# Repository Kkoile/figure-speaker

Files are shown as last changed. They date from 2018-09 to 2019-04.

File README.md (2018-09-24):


# Figure Speaker
This project is a Raspberry Pi based audio player which plays songs or audiobooks depending on a NFC Tag which is placed on the player. The NFC Tags can be attached to the bottom of a figure. This is an intuitive way for children to select the audiobooks they want to here based on the figures they associate with it.

The main feature of this project is a Spotify integration which lets you access all your favourite songs and audio books you already pay for every month.
By using the audio server [Mopidy](https://www.mopidy.com/) internally, further cloud services can be integrated really easily.
Box

## Feature List
 - Spotify integration
 - Easy to maintain and register figures through a web application
 - Portable by using a power bank
 - Play local mp3 files
 - Configure volume
 - Max volume is configurable
 - Define what happens after the figure is replaced on the audio player
   - Play the track from the beginning
   - Play the track where you left off
 - Easy to connect to new WiFi by creating an AdHoc network if the box cannot connect to WiFi
 - Update Manager which will allow you to receive the latest features without opening the box
 - Open for other cloud services
 - Automated tests to ensure quality

### Spotify Integration
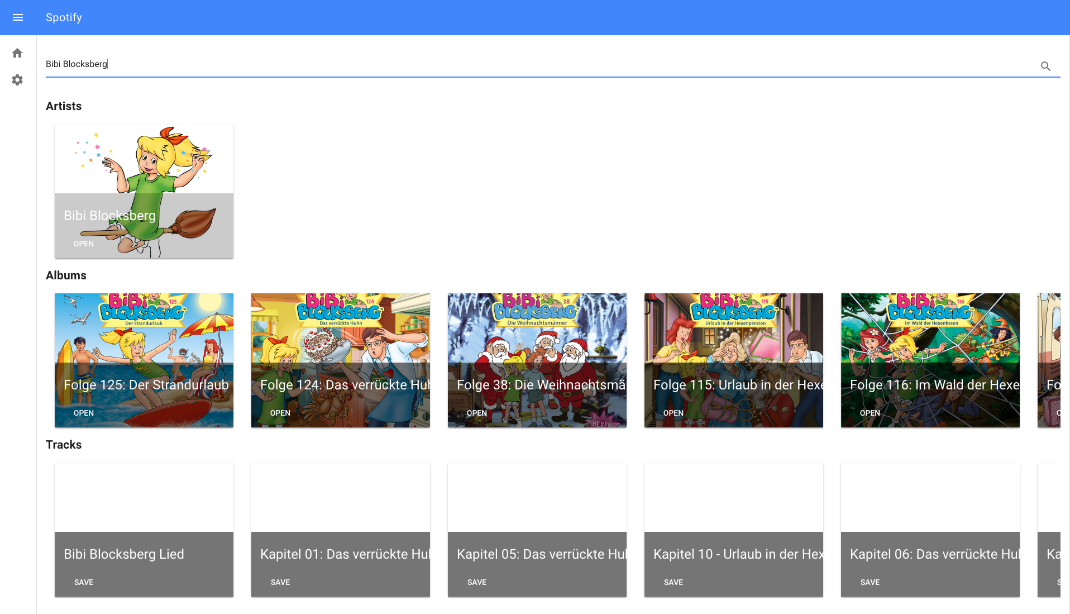
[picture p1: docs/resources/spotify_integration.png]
Spotify Integration


### Settings
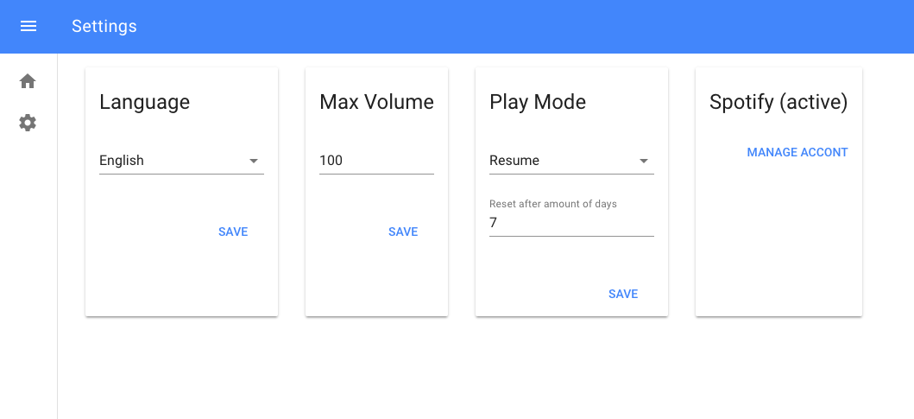
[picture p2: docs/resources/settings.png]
Settings


## Manual
See [Manual](docs/manual.md) for finding out how to use figure-speaker.

## Setup
See [Setup](docs/setup.md) for setting up the Raspberry Pi.

## Assembly
In chapter [Assembly](docs/assembly.md) I documented instructions how to build the hardware of the figure speaker.

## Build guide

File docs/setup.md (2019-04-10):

# How to Setup Figure-Speaker on a Raspberry Pi Image
These steps need to be followed in order to setup a raspberry pi image with the figure speaker environment. 
## Flash Raspberry Pi Image
The project is only tested with a raspbian image. However, other raspberry pi images should work as well.

Follow the instructions at [Raspberry Pi Setup Instructions](https://www.raspberrypi.org/documentation/installation/installing-images/) in order to flash an image. 
Download the lite image from [Raspberry Pi Downloads](https://www.raspberrypi.org/downloads/raspbian/). There is no need for the Desktop version, because the figure-speaker won't have a display attached.

Connect the SD card of your raspberry pi to your computer and flash the image via etcher.

### Create an SSH File
Create an empty file named `ssh` at root level of the sd card in order to access the raspberry pi later on.

### Provide WiFi Credentials (optional)
In order to directly access your raspberry pi over via ssh, you can provide the wifi credentials on sd card level. Without doing this you need to plug in your raspberry pi to your network via ethernet.

Create a file called `wpa_supplicant.conf` at root level of the sd card. Edit the file and place the following content with your modifications regarding the credentials:
```
country=DE
ctrl_interface=DIR=/var/run/wpa_supplicant GROUP=netdev
update_config=1

network={
    ssid="<SSID>"
    psk="<PASSWORD>"
}

```

### Start Raspberry Pi
Put the sd card into your raspberry pi and start it. It should connect to the configured wifi automatically.
Connect to the raspberry pi via ssh:
```
ssh pi@raspberrypi.local
```
Use the default password `raspberry` for authentication.
You should directly change the default password by entering the command `passwd`

From now on, you have two options: Either download and execute a setup script, which will execute every step necessary automatically, or do each step manually.
If you decide for the automatic script, all you have to do is to execute the following command and then restart the raspberry pi:
```
curl https://raw.githubusercontent.com/Kkoile/figure-speaker/master/setup.sh -o ~/setup.sh | ~/setup.sh
```
If you want to execute each step manually, follow the following commands on this page.

## Set Audio Volume to Maximum
The volume will be handled later by our application. In order to be able to get the maximum volume you should set it on the raspberry pi:
```
amixer set PCM -- 100%
```

## Enable SPI Interface
Type `sudo raspi-config` and go to `Interfacing Options`. Select `SPI` and make sure to enable it. 

## Install Mopidy
Mopidy is the audio server which connects to spotify and other providers. You can find more about mopidy [here](https://docs.mopidy.com/en/latest/).
In order to install mopidy on the raspberry pi follow the [instructions](https://docs.mopidy.com/en/latest/installation/debian/#debian-install).

Depending on the mopidy extensions you want to include you should install them. For example the spotify extension:
```
sudo apt-get install mopidy-spotify
``` 

Modify the file `~/.config/mopidy/mopidy.conf` and add the following lines to it:
```
[local]
media_dir = ~/.config/figure-speaker/files
```
Run `mopidy local scan` in order for mopidy to scan the files in there.

### Install MPC (Optional)
In order to test if mopidy is working, you can install a mopidy client like `mpc`:
```
sudo apt-get install mpc
```
This allows you to play mp3 files on your raspberry pi, or if already configured, extensions like spotify.
For the full documentation type `man mpc`. If you only want to test the audio output you can use the following code snippet:
```
curl https://www.sample-videos.com/audio/mp3/crowd-cheering.mp3 -o test.mp3
mpc add file:///home/pi/test.mp3
mpc play
```
Use `mpc stop` to stop playing the current audio file.

## Install Node.js
Node.js is the environment in which figure-speaker is written. Hence, to be able to execute the application you need to install it. 
```
curl -sL https://deb.nodesource.com/setup_8.x | sudo -E bash -
sudo apt-get install -y nodejs
```
Change the directory of installing global npm modules, in order to reduce permission errors. Follow this [link](https://docs.npmjs.com/getting-started/fixing-npm-permissions#option-two-change-npms-default-directory) to do so.

## Install Figure-Speaker
Figure-Speaker is written as a global npm module. So we can install it by executing the following command:
```
sudo npm install -g figure-speaker
```
Don't mind the vast amount of error logs...

You can test the installation by typing `figure-speaker` in the command line. This should start the server. The frontend should now be available at `http://figure-speaker:3000` or `http://figure-speaker.local:3000` (MacOsX).

We want our application to always start when booting raspberry pi. To achieve this, we create a service file which we can then manage with `systemctl`.
Create a file `figure-speaker.service`:
 ```
 sudo touch /etc/systemd/system/figure-speaker.service
 sudo chmod 664 /etc/systemd/system/figure-speaker.service
 ```
And paste the following content in it. You should change the spotify credentials according to your spotify app.
//TODO: link to another chapter where this is explained
```
[Service]
WorkingDirectory=/home/pi/
ExecStart=/home/pi/.npm-global/bin/figure-speaker
Restart=always
StandardOutput=syslog
StandardError=syslog
SyslogIdentifier=figure-speaker
User=pi
Group=pi
Environment=NODE_ENV=production SPOTIFY_CLIENT_ID=<SPOTIFY_CLIENT_ID> SPOTIFY_CLIENT_SECRET=<SPOTIFY_CLIENT_SECRET> GPIO_INCREASE_VOLUME_BUTTON=27 GPIO_DECREASE_VOLUME_BUTTON=22

[Install]
WantedBy=multi-user.target
```

Execute the following command:
```
sudo systemctl enable figure-speaker
```
Now, either start the service directly with `sudo systemctl start figure-speaker`, or reboot the raspberry pi.
 
You can always see the current logs by executing `journalctl -u figure-speaker -f`

## Install Update Manager
```
sudo npm install -g figure-speaker-update-manager
```
Create a file `figure-speaker-update-manager.service`:
 ```
 sudo touch /etc/systemd/system/figure-speaker-update-manager.service
 sudo chmod 664 /etc/systemd/system/figure-speaker-update-manager.service
 ```
And paste the following content in it.
```
[Service]
WorkingDirectory=/home/pi/
ExecStart=/home/pi/.npm-global/bin/figure-speaker-update-manager
Restart=always
StandardOutput=syslog
StandardError=syslog
SyslogIdentifier=figure-speaker-update-manager
User=pi
Group=pi
Environment=NODE_ENV=production 

[Install]
WantedBy=multi-user.target
```

Execute the following command:
```
sudo systemctl enable figure-speaker-update-manager
```
Now, either start the service directly with `sudo systemctl start figure-speaker-update-manager`, or reboot the raspberry pi.
 
You can always see the current logs by executing `journalctl -u figure-speaker-update-manager -f`

## Install WiFi Connector
```
sudo npm install -g figure-speaker-wifi-connector
```
Create a file `figure-speaker-wifi-connector.service`:
 ```
 sudo touch /etc/systemd/system/figure-speaker-wifi-connector.service
 sudo chmod 664 /etc/systemd/system/figure-speaker-wifi-connector.service
 ```
And paste the following content in it.
```
[Service]
WorkingDirectory=/home/pi/
ExecStart=/home/pi/.npm-global/bin/figure-speaker-wifi-connector
Restart=always
StandardOutput=syslog
StandardError=syslog
SyslogIdentifier=figure-speaker-wifi-connector
User=root
Group=root
Environment=NODE_ENV=production 

[Install]
WantedBy=multi-user.target
```

Execute the following command:
```
sudo systemctl enable figure-speaker-wifi-connector
```
Now, either start the service directly with `sudo systemctl start figure-speaker-wifi-connector`, or reboot the raspberry pi.
 
You can always see the current logs by executing `journalctl -u figure-speaker-wifi-connector -f`

## Configure Ad Hoc Wifi
//TODO document how to configure ad hoc network and expose figure-speaker-wifi-connector

https://lcdev.dk/2012/11/18/raspberry-pi-tutorial-connect-to-wifi-or-create-an-encrypted-dhcp-enabled-ad-hoc-network-as-fallback/

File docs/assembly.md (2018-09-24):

# Assembly
In this chapter you will find instructions about how to build the hardware of figure speaker.
## Connect Raspberry Pi to Modules
This section instructs you how to connect the Raspberry Pi to the different hardware modules. 

### What you need
- [Raspberry Pi 3](https://www.amazon.de/Raspberry-Pi-Model-ARM-Cortex-A53-Bluetooth/dp/B01CD5VC92/)
- [SD Card](https://www.amazon.de/SanDisk-Ultra-microSDHC-Speicherkarte-Adapter/dp/B073S9SFK2/)
- [RFID Reader](https://www.amazon.de/gp/product/B01M28JAAZ/)
- [Power Bank](https://www.amazon.de/gp/product/B00FAU7ZB2)
- [Micro USB Cable](https://www.amazon.de/gp/product/B01NAMTC5T)
- [Jumper Cable](https://www.amazon.de/gp/product/B00OL6JZ3C)
- [Buttons](https://www.amazon.de/gp/product/B0749KNQNH)
- 2x 1 kΩ Resistor
- [Speaker](https://www.amazon.de/gp/product/B073XH8KK8)
- [Amplifier](https://www.amazon.de/HER-Digital-Amplifier-PAM8403-Stereos/dp/B073HFGZQC)
- [Aux Cable](https://www.amazon.de/gp/product/B00DRCTB58)
- [Breadboard](https://www.amazon.de/gp/product/B0728HZHTR/)
- [Copper wire](https://www.amazon.de/gp/product/B0043DQ7WK)

1) If not already done, you need to solder the pins to the Raspberry Pi and the RFID Reader.
2) Connect the aux cable to the amplifier module. I cut of one end of the aux cable and strip of the isolation. Then the copper wire needs to be soldered to the amplifier.
3) Solder the speakers to the amplifiers.
4) Connect circuit bord to Raspberry Pi. I used jumper cables for connecting the the modules.
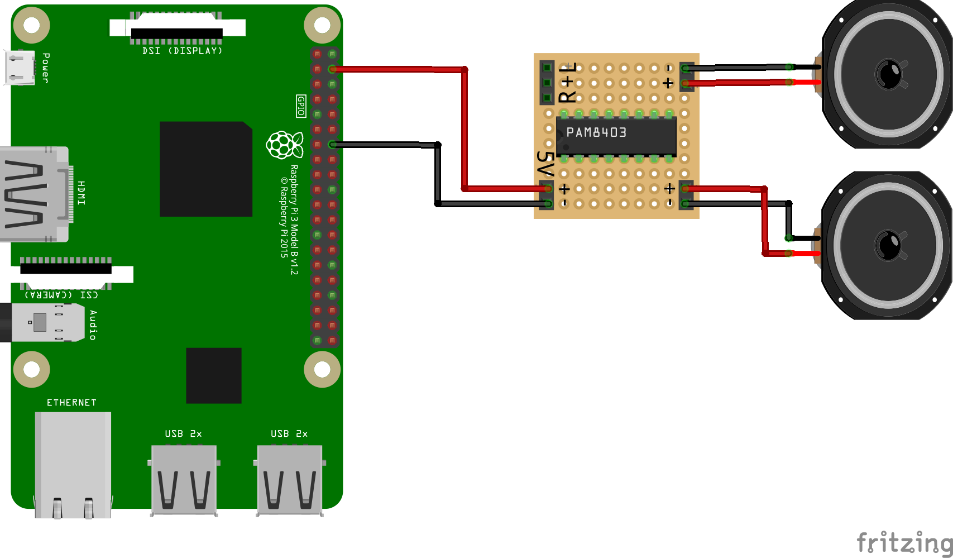
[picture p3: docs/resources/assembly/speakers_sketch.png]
Speakers

5) Create a circuit board with resistors for the volume buttons. You can find a sketch of the circuit board in the image below. I used 1 kΩ resistors. Make sure that the cables to the buttons are long enough to be placed where you want them to be.
6) Connect this circuit board to Raspberry Pi.
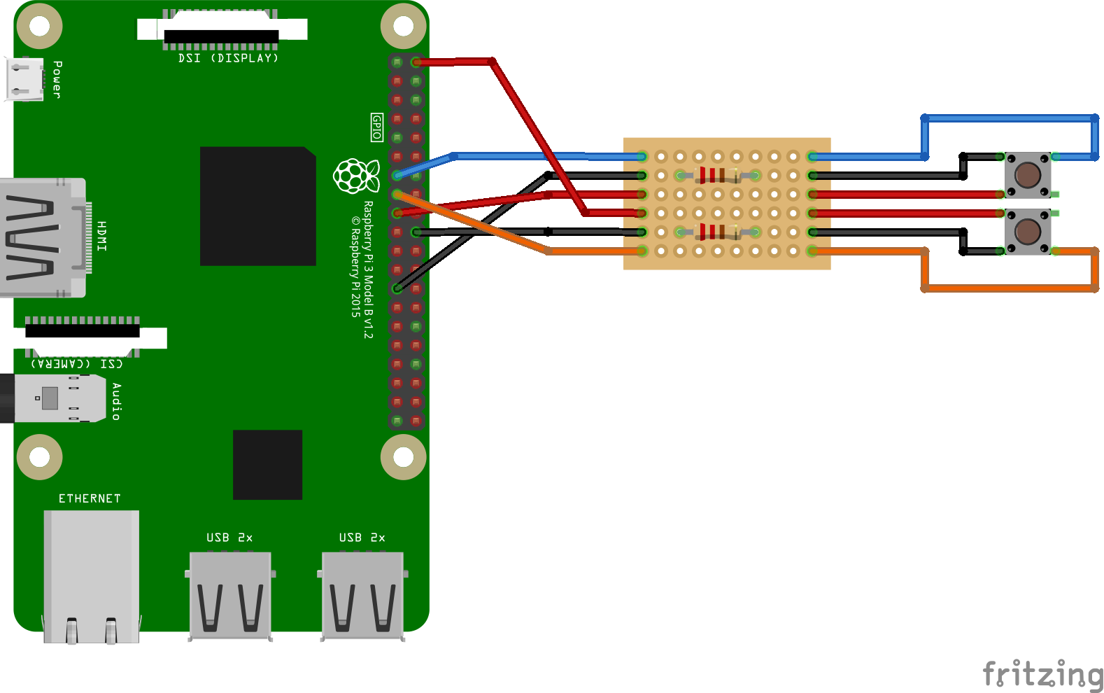
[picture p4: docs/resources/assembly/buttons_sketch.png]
Buttons

7) Connect RFID Reader to Raspberry Pi.
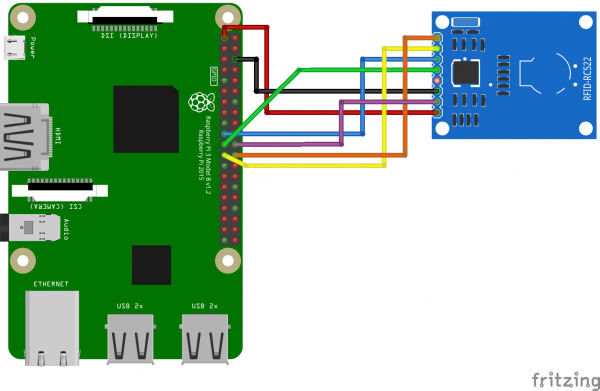
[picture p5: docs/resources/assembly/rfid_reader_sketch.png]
RFID Reader

Image is taken from "https://tutorials-raspberrypi.de/raspberry-pi-rfid-rc522-tueroeffner-nfc/"

after you have wired everything, you can test if it works. In order to setup the Raspberry Pi itself from a software point of view, see chapter [Setup](./setup.md). I advise you to do the final wiring while building the box (see below). Otherwise it will be complicated to place the modules in the box.

## Build the Box
I know that there are a lot of ways to build a simple box and I am not a carpenter. So this way to build a wooden box might not be the best, but it is simple and works. However, feel free to give feedback or adjust the instructions to your needs.

Please Note: The wooden parts of the box don't need to be perfectly cut, because I wrap the whole box with foam plates, in order to make them "child safe" and robust against falling to the ground etc. 
 
The sizes of this box depend on the power bank you use and the size of the speakers. That's why there are no measures for the outlets of the power bank in order to charge it or turn it on and off.
### What you need
- 4x square mouldings: 20mm * 20mm * 140mm
- 4x captive nuts: M4 * 6
- 4x countersunk threaded screw: M3 * 16mm
- 4x wood plates for the side: 150mm * 140mm * 4mm
- 2x wood plates for the bottom/top: 150mm * 150mm * 4mm
- 20x screw spax: M4 * 12mm
- 4x countersunk threaded screw: M2 * 10mm incl. nuts
- 10x countersunk threaded screw: M3 * 10mm incl. nuts
- 4x cylinder head threaded bolt: M3 * 16mm incl. 12 nuts
- metal perforated tapes
- foam plates: about 10mm thick

### Blueprints
Two bottom / top plates:
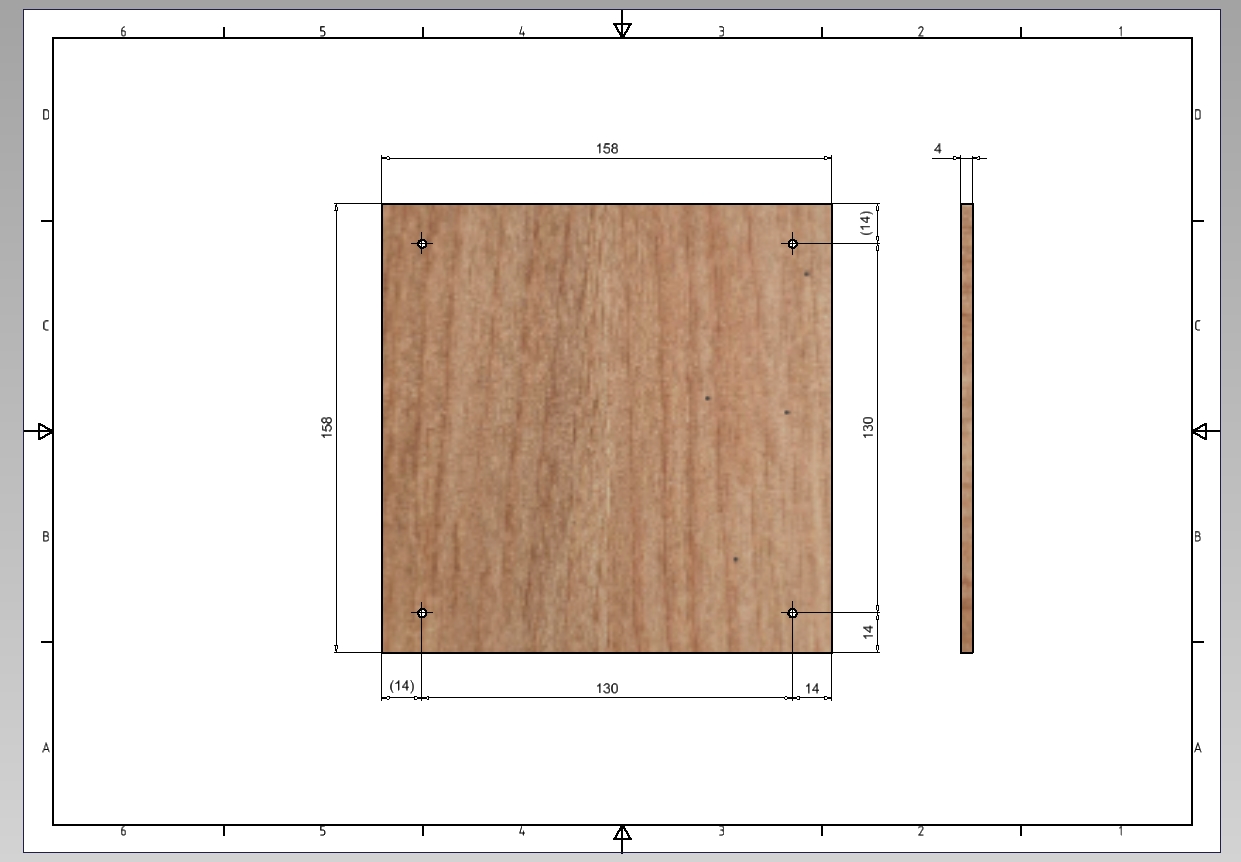
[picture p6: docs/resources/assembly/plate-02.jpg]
Bottom / Top Plates

Two side plates:
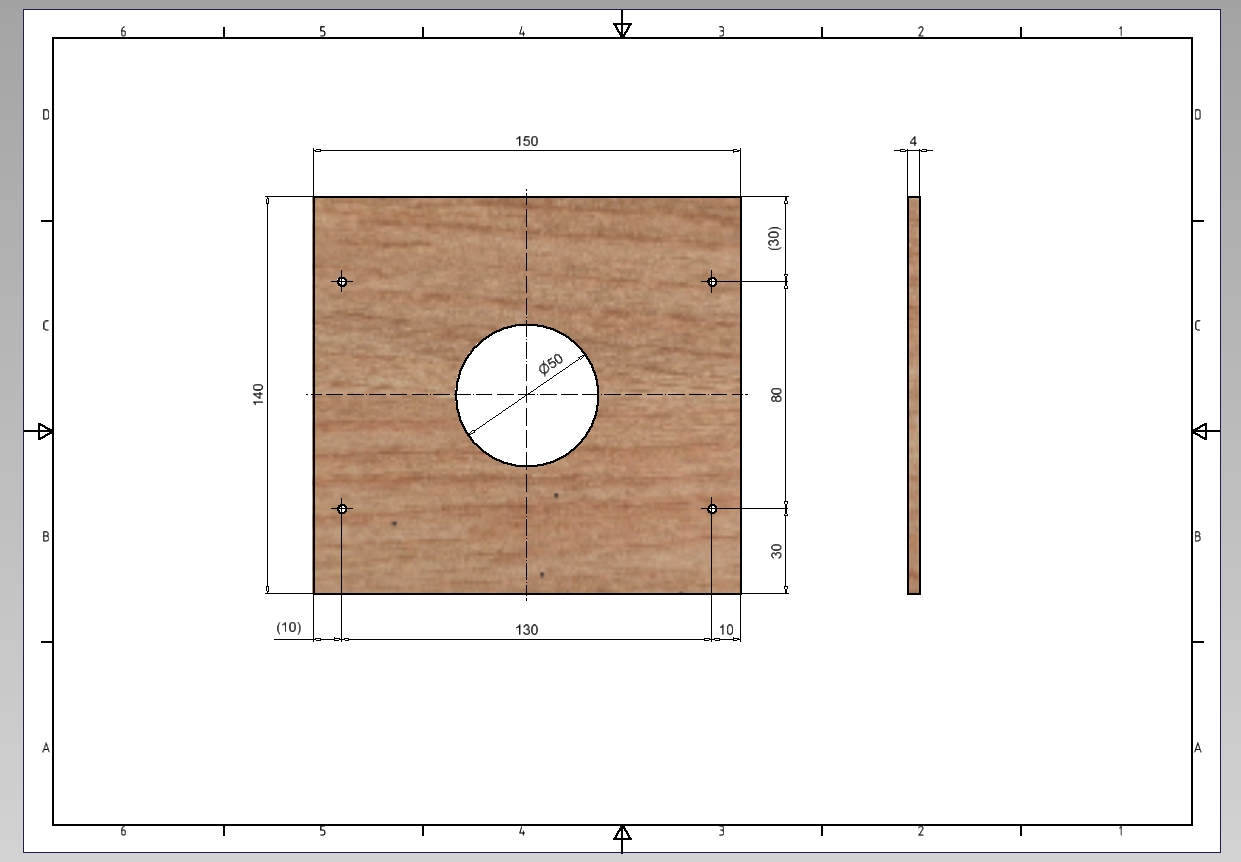
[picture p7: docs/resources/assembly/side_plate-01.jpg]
Side Plates

Front plate:
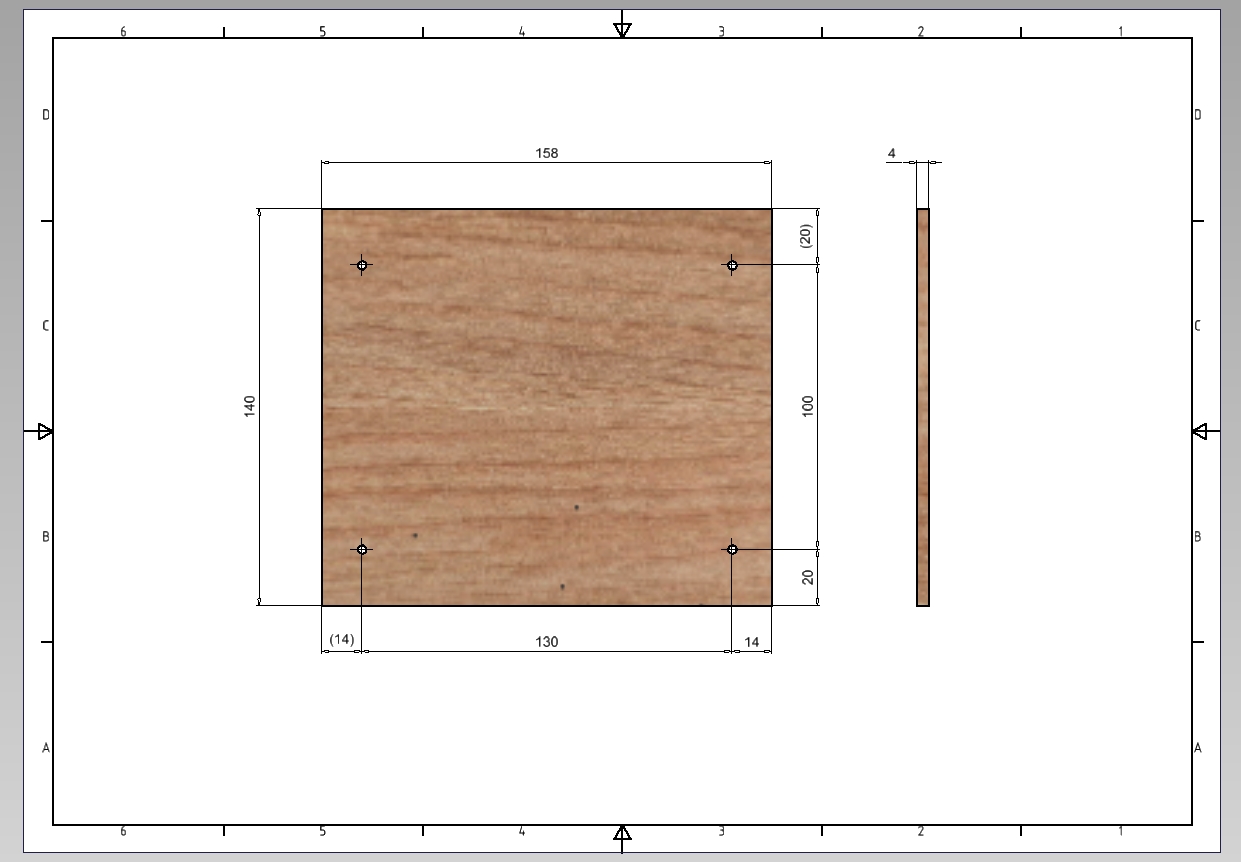
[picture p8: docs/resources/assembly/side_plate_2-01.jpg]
Front Plate

Back plate (notice the outlet for the power bank):
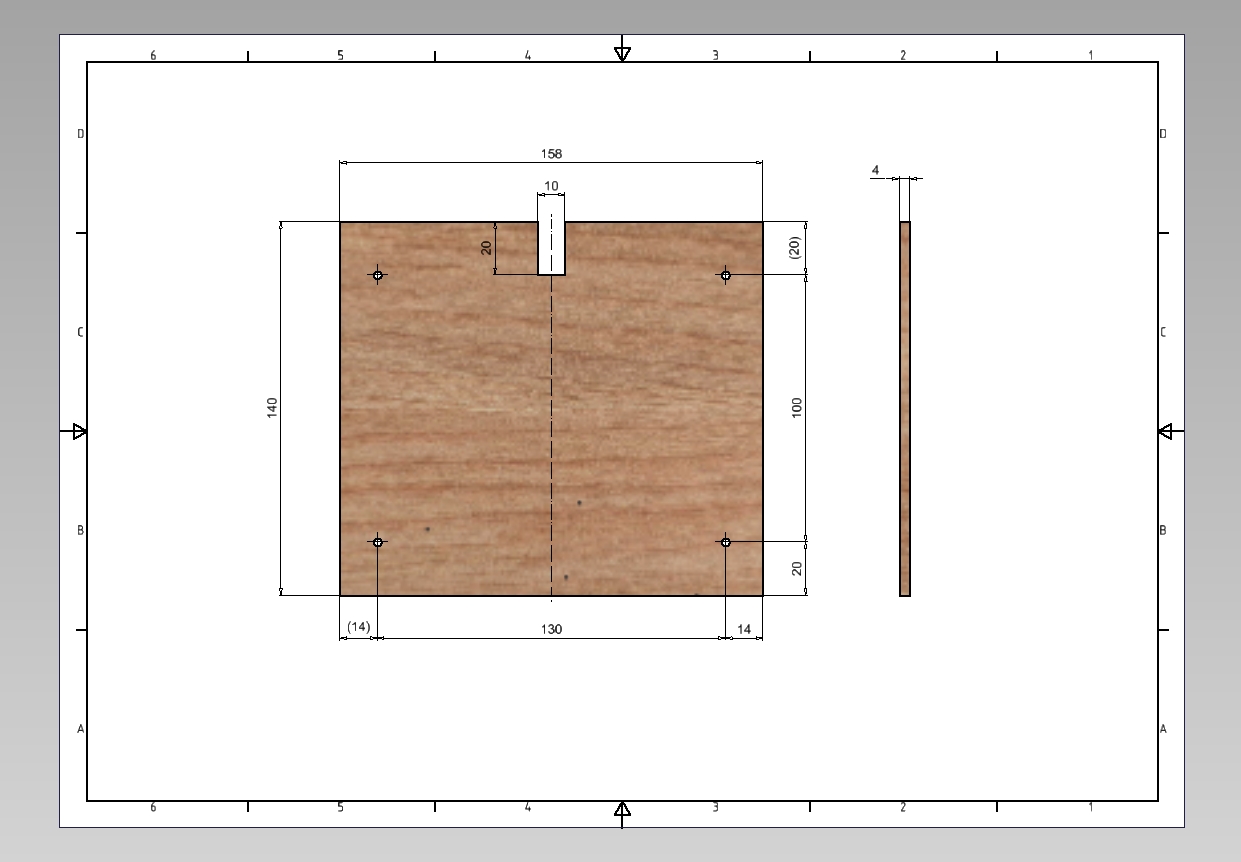
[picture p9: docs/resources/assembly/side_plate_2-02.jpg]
Back Plate

Four Struts:
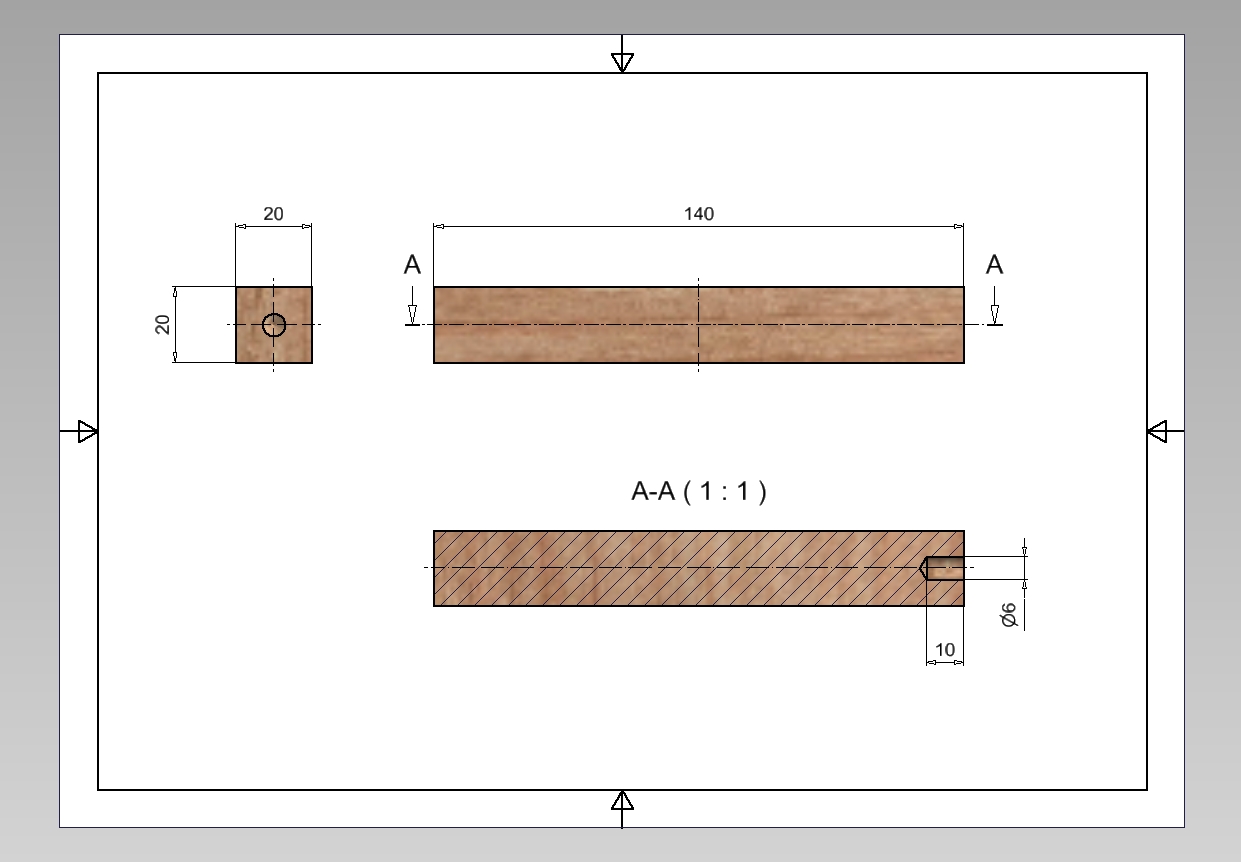
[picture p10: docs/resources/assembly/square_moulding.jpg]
Struts


### Assemble
1) Drill a 6mm hole about 10mm deep into one end of each square mouldings. Punch the captive nuts in these holes.
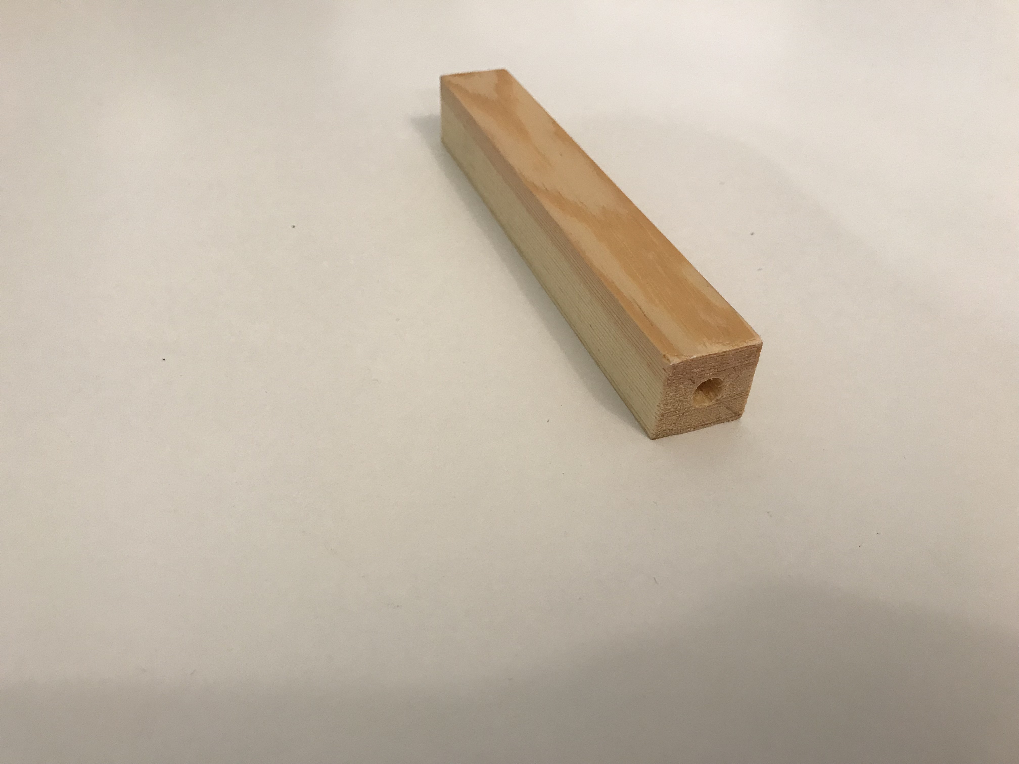
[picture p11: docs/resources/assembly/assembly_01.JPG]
Hole in Square Mouldings

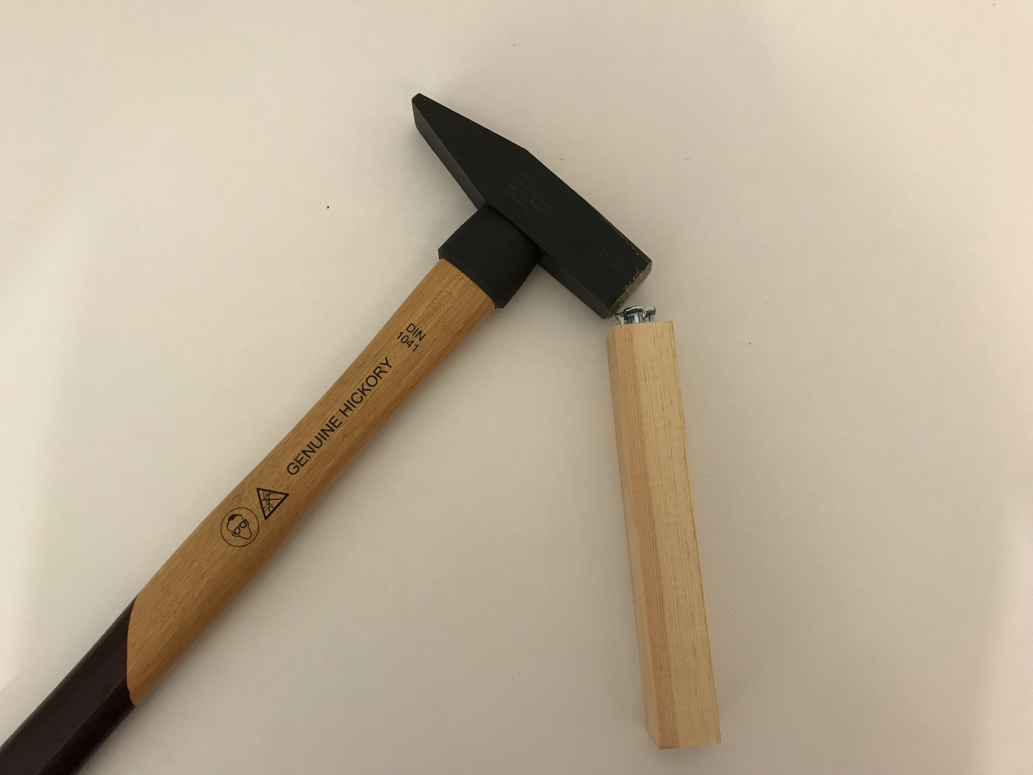
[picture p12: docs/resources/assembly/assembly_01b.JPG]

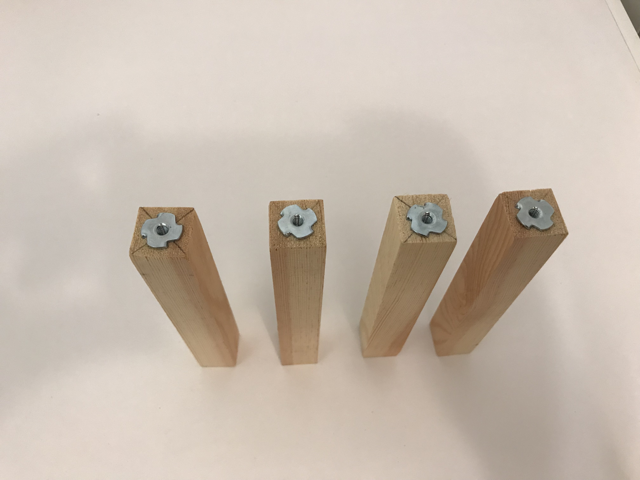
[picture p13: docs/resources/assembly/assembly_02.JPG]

2) Drill a hole in the middle of two of the side plates. The speakers will be placed in these holes later on. In my case the diameter is 50mm, but it depends on the speakers you use.
Drill four 3mm holes in the corners next to the holes to attach the speakers later. Because the position of these holes also depend on your speakers, I excluded them from the blueprints.
3) Drill four 2mm holes in another side plate (the back). These will be used to attach the Raspberry Pi to the box. Beware of the position of the Pi: The power bank has to be placed underneath.
4) Drill a hole in the top plate for the cables of the RFID reader; about 20mm * 10mm. In addition to that, you need four 3mm holes to connect the RFID Reader to the box.
5) Drill holes for the outlets of the powerbank: USB input and on / off button.
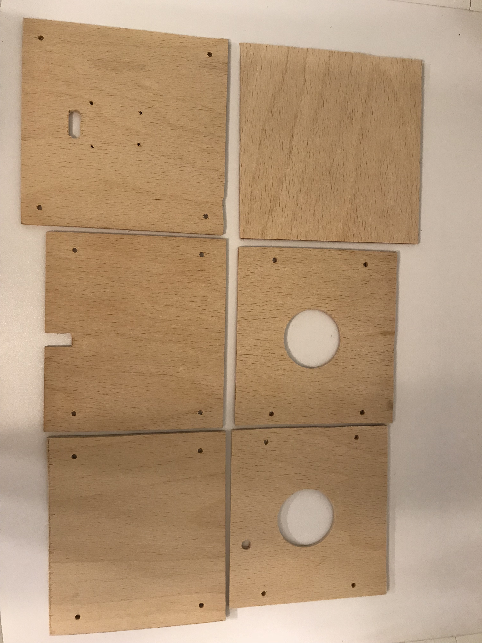
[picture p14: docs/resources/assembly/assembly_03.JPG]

6) Screw the side plates to the square mouldings. The captive nuts should be on the buttom. Make sure that the plates with the speaker holes are facing each other. Use the screw spax for this. Don't screw them to close to the edge of the square mouldings, because screws need to come from the top and they shouldn't conflict.
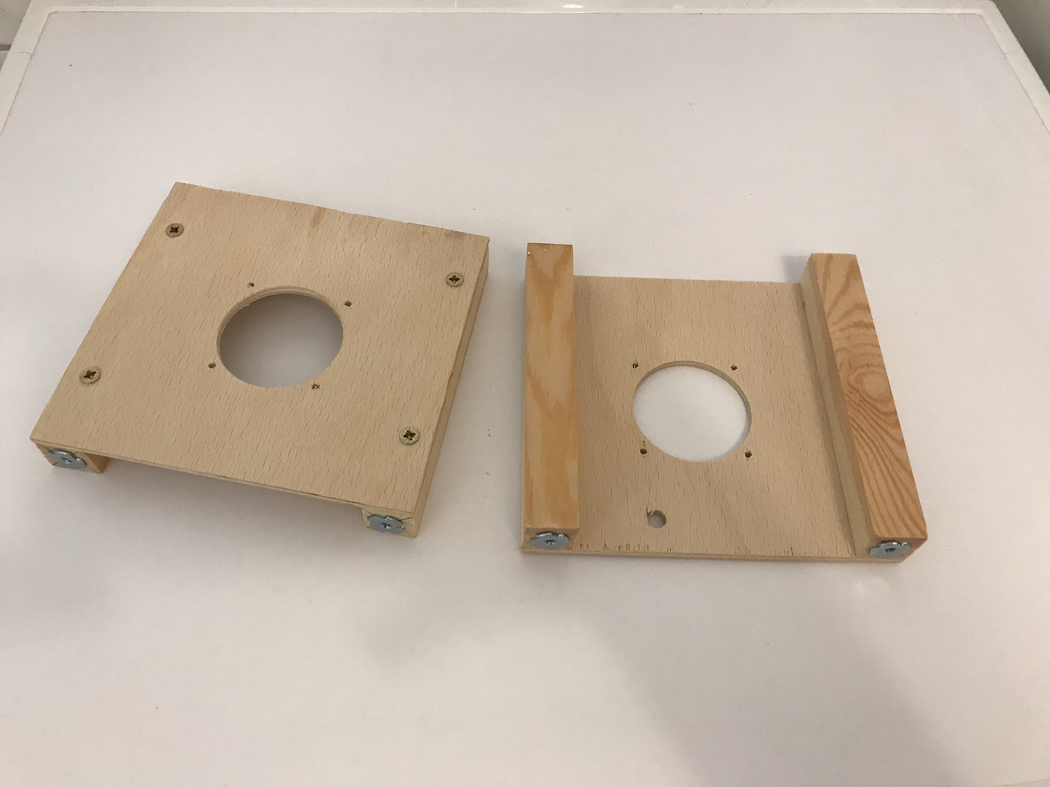
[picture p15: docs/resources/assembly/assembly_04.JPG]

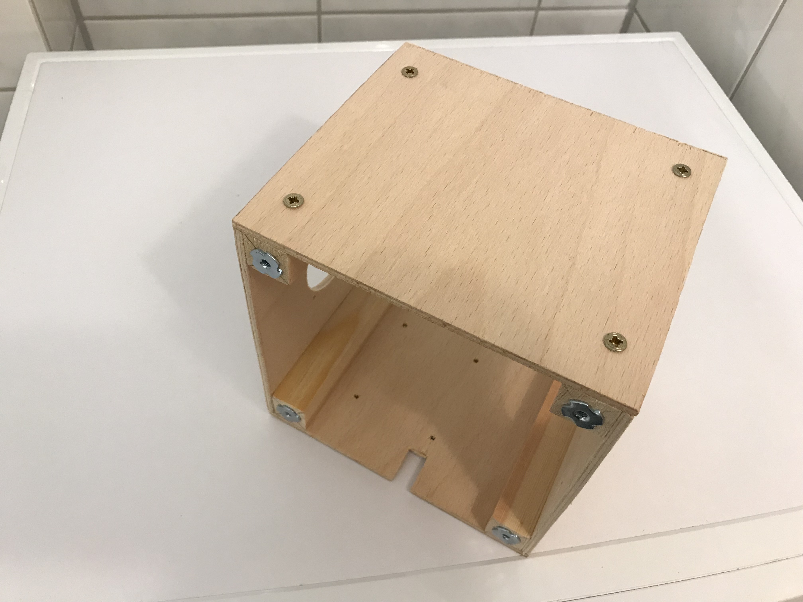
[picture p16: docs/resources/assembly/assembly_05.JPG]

7) Attach the Raspberry Pi to the back plate. Use 4x countersunk threaded screw: M2 * 10mm incl. nuts for this purpose.
8) Attach the speakers to the side plates. Use 8x countersunk threaded screw: M3 * 10mm incl. nuts for this purpose.
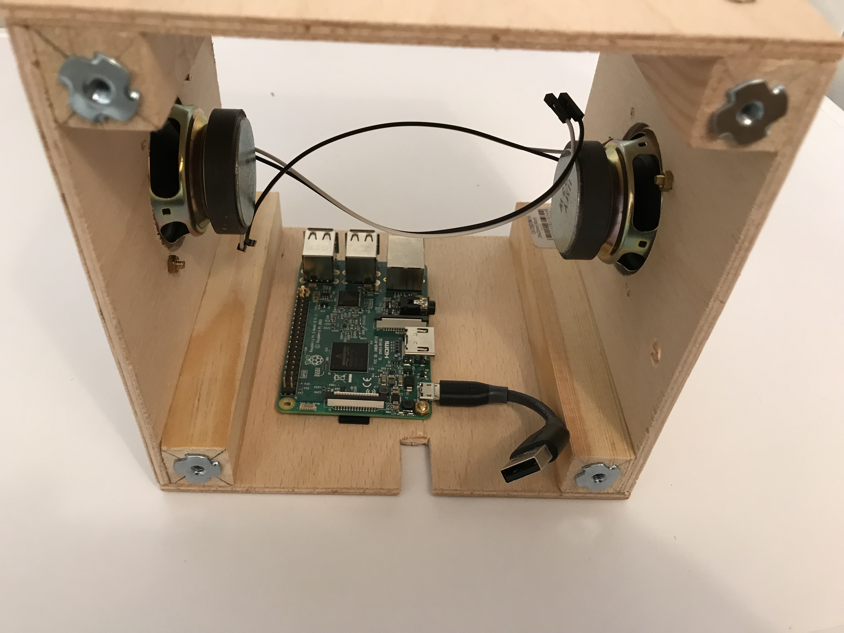
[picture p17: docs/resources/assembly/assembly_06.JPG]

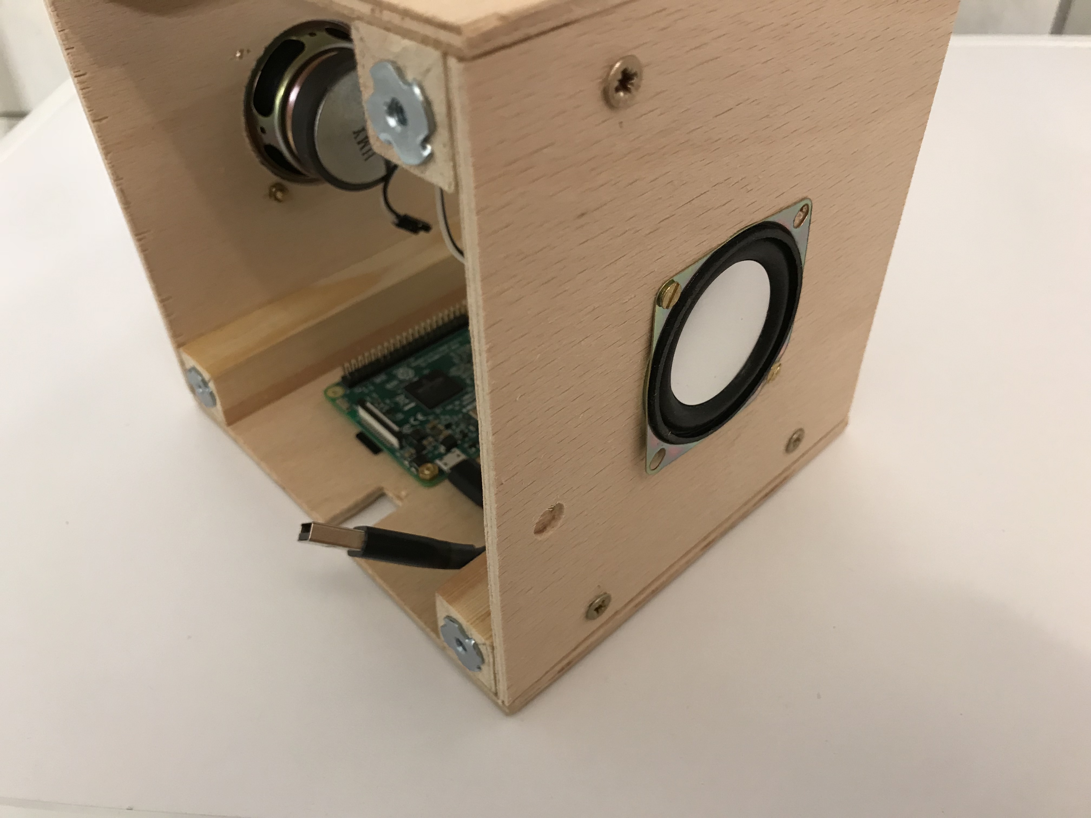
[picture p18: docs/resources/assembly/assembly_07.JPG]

9) Attach the RFID Reader to the top plate. I used four countersunk threaded screw M3 * 16mm for this. Use three nuts for each screw in order to place the RFID Reader about 10mm above the box. This is done because the box will be wrapped with 10mm thick foam plates and the RFID Reader should be aligned with these plates.
10) Screw the top plate to the square mouldings with four screw pax M4 * 12mm
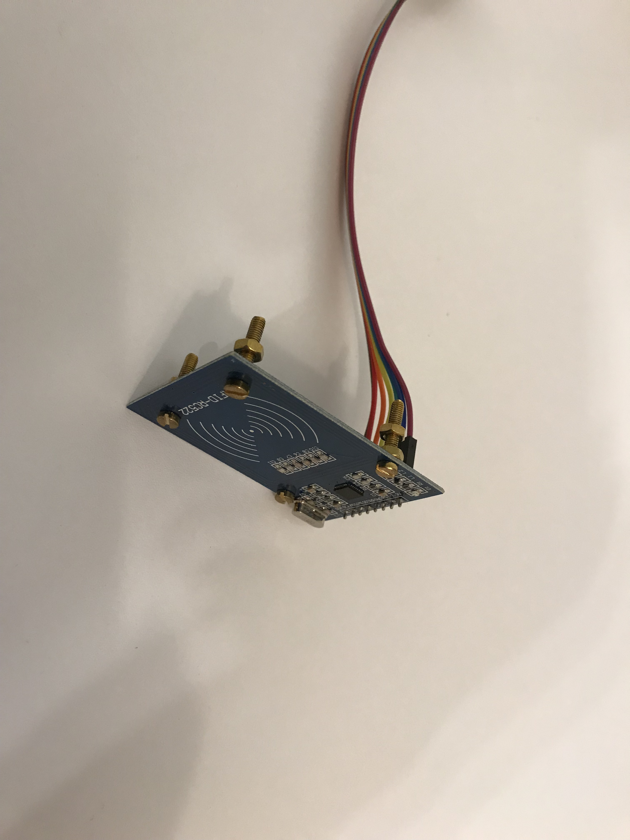
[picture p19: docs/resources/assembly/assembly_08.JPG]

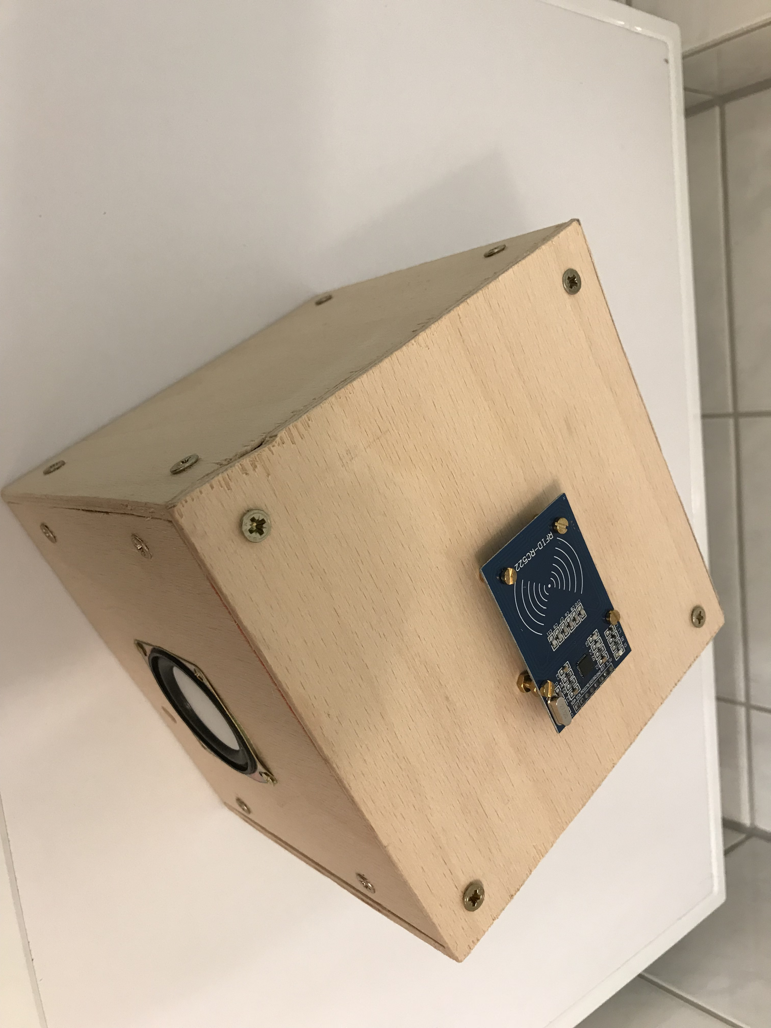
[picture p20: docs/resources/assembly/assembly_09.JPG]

11) Form the ears of the figure speaker. I use copper wire which is thick enough so that you cannot bend it easily. At the bottom of the ears form a loop. The loop is used to screw the ears to the top of the box with a countersunk threaded screw, a nut and a washer. Drill another hole next directly next to it where the cables of the buttons can go into the inside of the box.
Then attach the buttons to the ears.
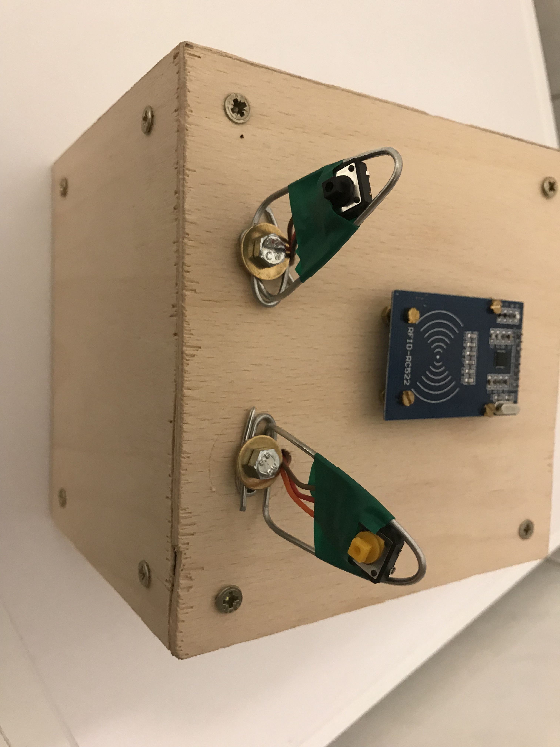
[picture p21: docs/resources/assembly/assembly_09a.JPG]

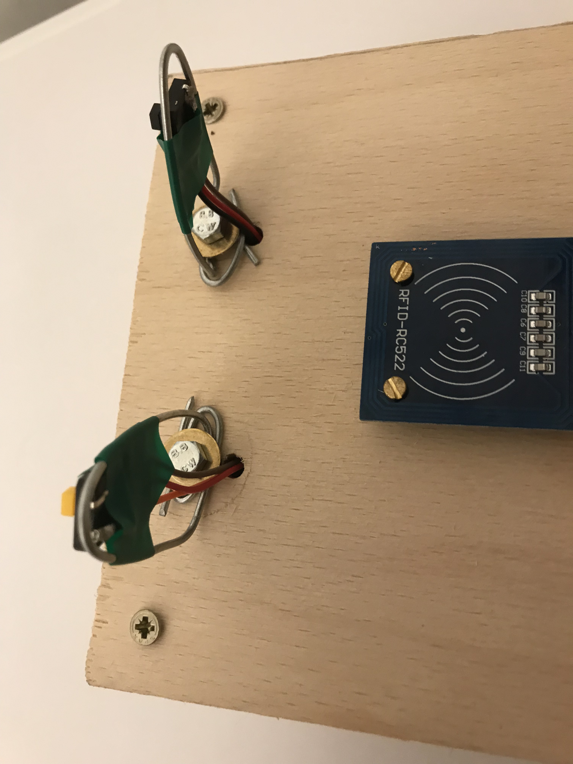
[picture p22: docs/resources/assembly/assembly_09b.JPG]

12) Wire the modules to the Raspberry Pi.
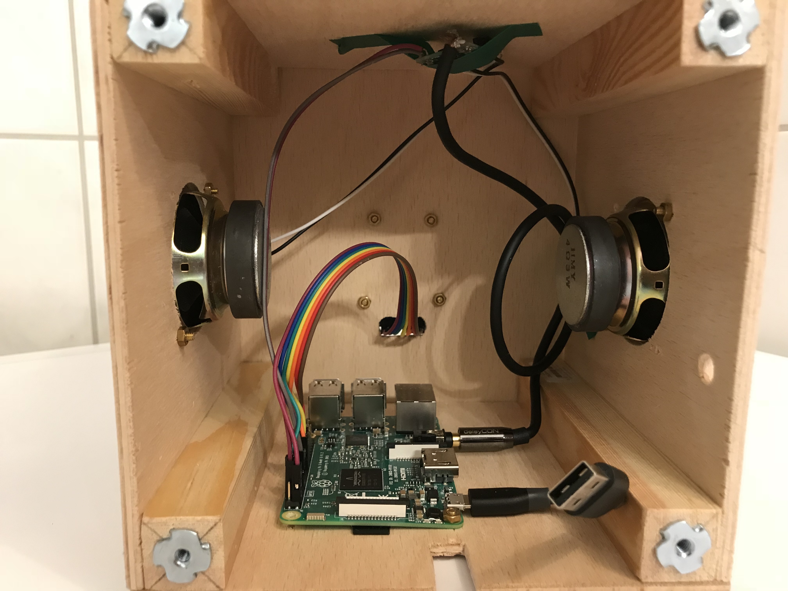
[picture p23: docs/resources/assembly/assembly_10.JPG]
Wire Modules

13) Drill 4mm holes in the corners of the bottom plate. They are used to screw the bottom plate to the captive nuts in the square mouldings.
14) Attach the power bank to the bottom plate. I used metal perforated tapes to realize this. These are bent over the power bank and screws hold the tape to the bottom plate. I use two countersunk threaded screws: M3 * 10mm incl. nuts for this.
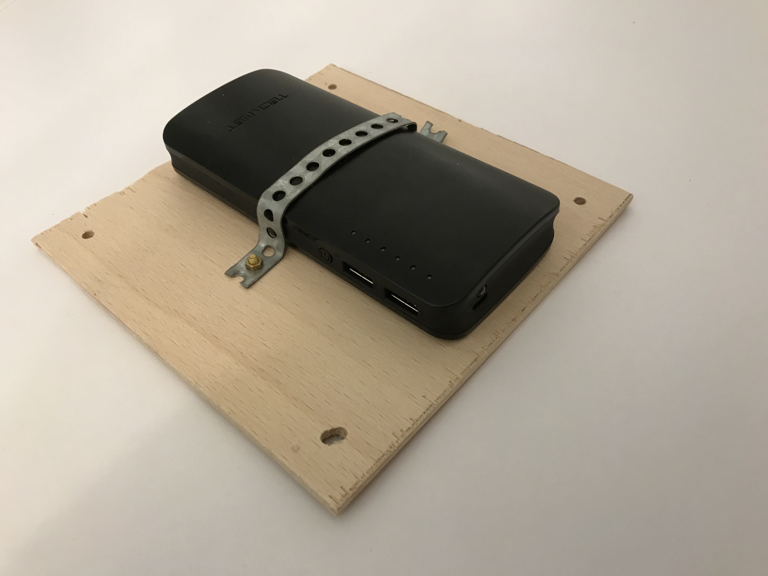
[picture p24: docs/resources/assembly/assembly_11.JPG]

15) Screw the bottom plate to the box with four countersunk threaded screws: M3 * 16mm.
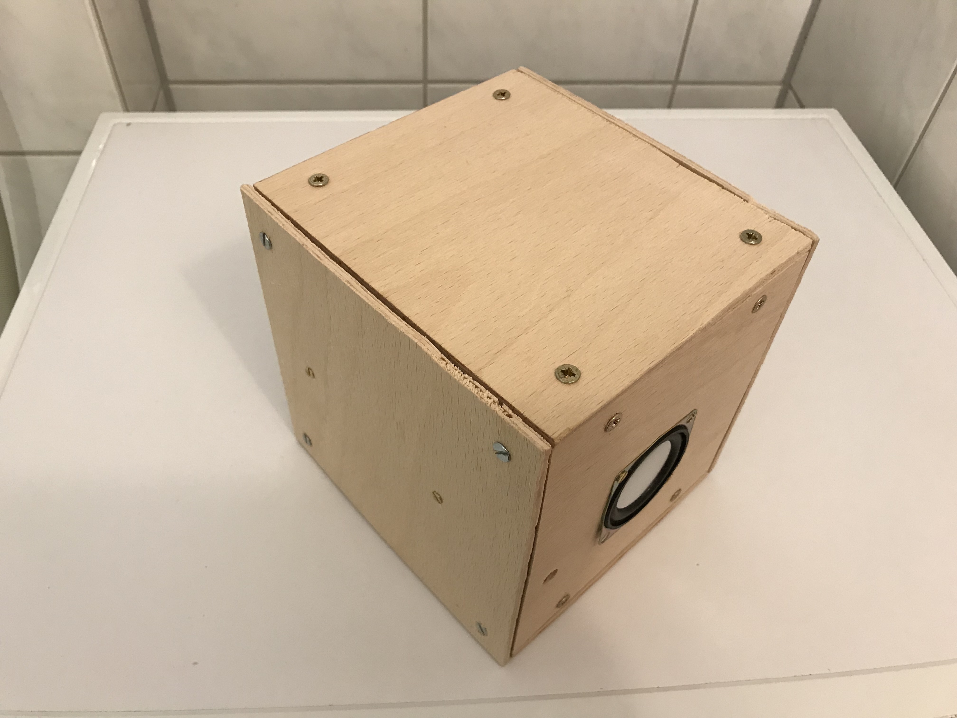
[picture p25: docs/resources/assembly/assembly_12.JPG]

16) Wrap everything with foam plates. Make sure that the plates align to each other and that there are no huge gaps. I used superglue to attach them to the box.
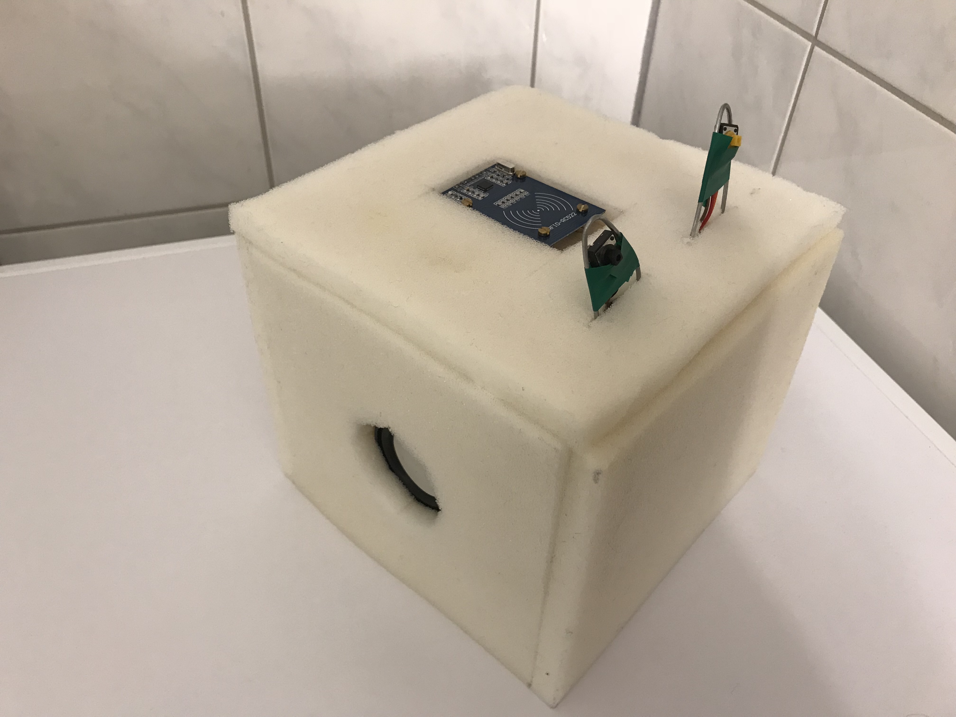
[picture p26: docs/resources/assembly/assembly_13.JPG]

17) Use fabric to sew a jacket for the box. I cut six plates with enough additional space at each side to tailor those pieces together. Make sure to leave a hole for the power outlet. And you can also think of additional holes for air circulation so that it doesn't no get too hot inside the box.
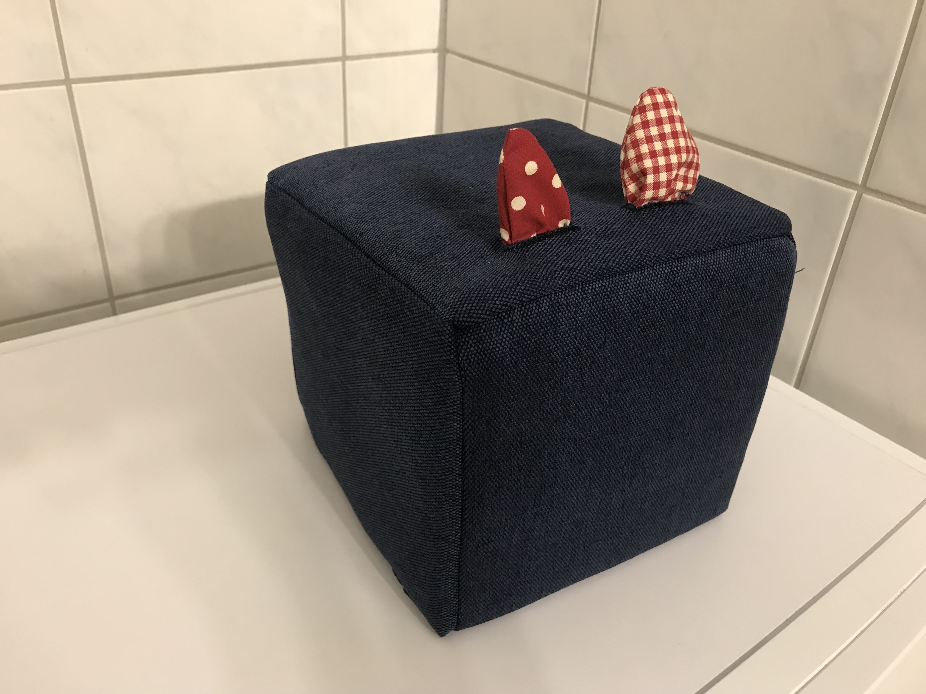
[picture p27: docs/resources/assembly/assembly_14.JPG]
Jacket

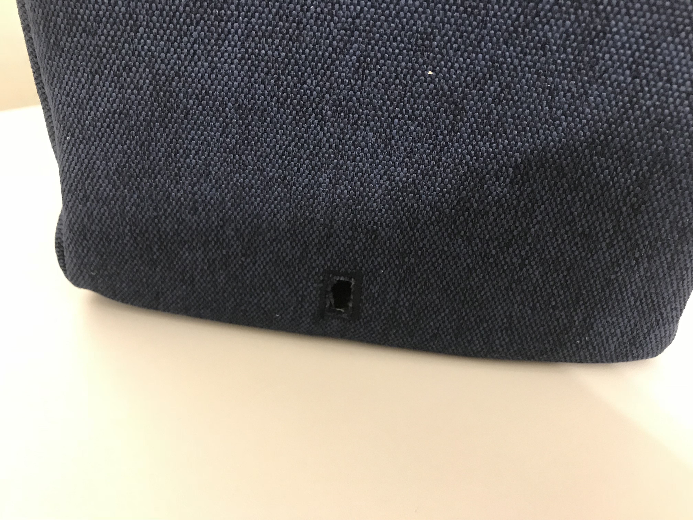
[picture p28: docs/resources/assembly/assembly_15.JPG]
Jacket with Hole


## Build the Figures
In order to build a figure you bascially only need an nfc tag and the figure.
### What you need
- [NFC Tags](https://www.amazon.de/gp/product/B01F02W45G)
- A Figure
- A Wooden Plate (optional)

If your figure does not have a good area already, where you can stick an NFC tag on, you should use a wooden plate where you glue the figure on. Then you can simply attach the NFC tag to this plate with glue (depending on the tag, they already have a sticky side).
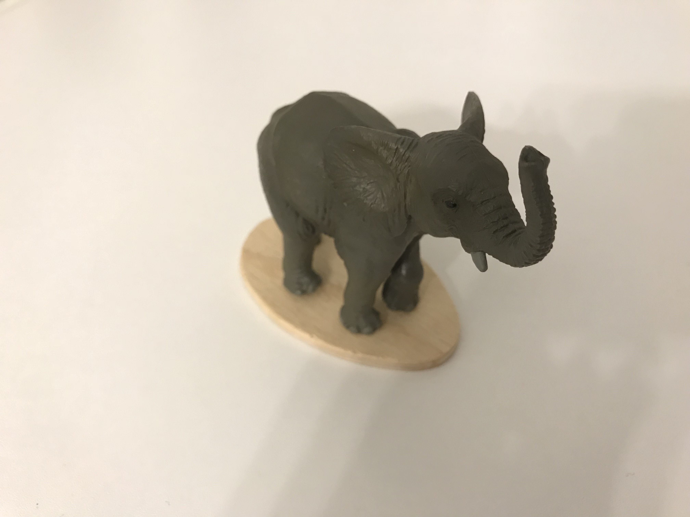
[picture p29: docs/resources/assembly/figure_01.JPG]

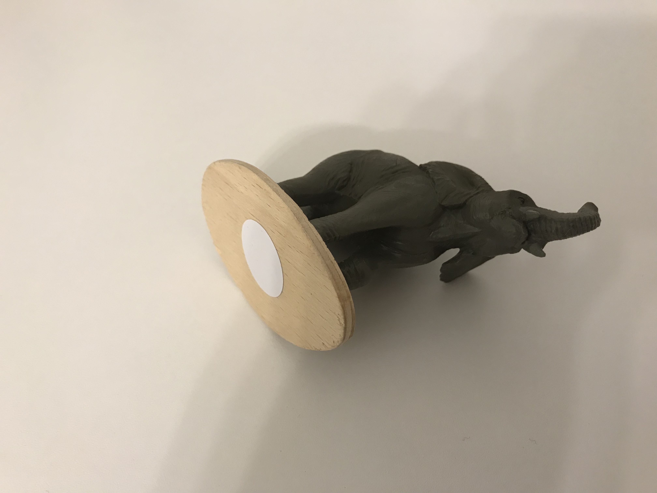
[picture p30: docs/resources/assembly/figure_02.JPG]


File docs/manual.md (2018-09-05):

# Manual
Here you find information about how to use figure-speaker.

Note: When I talk about a `figure` I always assume that this figure has an NFC tag attached to its bottom.
## Connect to Network
If you use figure-speaker for the first time, you need to connect it to your WiFi. The Raspberry Pi opens an AdHoc network named `Figure-Speaker`. Connect to it and you will automatically be redirected to a web page where all available WiFi networks are listed. Choose your network and provide its password. After you have connected it to the WiFi successfully, you can go to `http://raspberrypi.local:3000` where you can configure figure-speaker.

## Configure Figure Speaker
If figure-speaker is connected to your WiFi got to `http://raspberrypi.local:3000` (you need to be on the same network). Go to `Settings` tab on the left-hand side.

### Configure Spotify Credentials
In order to integrate with Spotify, you need to provide the credentials of your Spotify Premium account. Go to Spotify and choose `Manage Account`. Follow the instructions in order to receive the Client Id and Client Secret of your Spotify account. These are used by Mopidy to connect to Spotify (see more [here](https://www.mopidy.com/authenticate/)).

## Connect a Figure with an Audio Track
In order to connect a new or an existing figure with an audio track, place it on the top of figure-speaker. Then choose the track you want it play by providing the mp3 file name or browse through Spotify. If you found the preferred track press `Save`. The figure is now associated with this track. The next time you place this figure on the speaker, this track will be played.

## The Actual Use
If you want to listen to music via figure-speaker, make sure that it is turned on and connected to the network. Then simply place the preferred figure onto the speaker and the audio track associated with it will be played. You can stop the track by removing the figure from the top of your speaker.

What happens if you remove the figure, when the track was in the middle and replace it onto the speaker? This depends on the configuration. If your figure-speaker is configured to resume the track, then it will resume where you left off. But if the speaker is configured to reset the track, it will always be played from the beginning.

In order to change the volume you need to press either the "volume up" or "volume down" button. These are located in the ears of the figure-speaker. The smaller ear decreases the volume, while the bigger ear increases the volume.

If you need to recharge the figure-speaker plug in the cable to the power bank which is inside of the bank. Of course you can use the figure-speaker while charging.

And that's it! The figure-speaker is based on simplicity, to make it as intuitive for children as possible!

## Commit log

2018-05-21 fix mopidy seek problem that only the first track gets played
2018-07-16 [WIP] first styling with material design
2018-07-17 styling with material design
2018-07-22 only change volume when button is pressed and not when it is released
2018-07-22 remove custom test stage
2018-09-05 Document how to install figure-speaker-wifi-connector
2018-09-10 Include images for assembly documentation
2018-09-17 improve docs
    [buttons_sketch.fzz, speakers_sketch.fzz]
2018-09-24 Docs: Added Square Moulding Blueprint
2018-11-24 [Mopidy] skip to last played track in playlist
2018-11-24 [SaveFigure] stop playing current figure, before saving a new one fixes #9
2018-12-11 update buttons sketch
    [buttons_sketch.fzz]
2018-12-11 rename raspberrypi host name in setup script
2018-12-30 [Buttons] wind when pressed long enough fixes #20
2018-12-30 Rename `VolumeController` to `ButtonsController` and implement mopidy listener for wind actions
2019-02-20 [WindActions] Don't call `previous` in case track index is 0. Replay the current track instead
2019-02-20 [WindActions] do nothing on wind forwards if track is the last one
2019-09-08 fixed wind button tests and made them more stable
2020-01-22 add support for adafruit pn532shield (#30)
    * add support for adafruit pn532shield
    * split out arduino sketch into its own folder and explain what its there for, add serialport dependency
    * use let where appropriate
    * run lint:fix
